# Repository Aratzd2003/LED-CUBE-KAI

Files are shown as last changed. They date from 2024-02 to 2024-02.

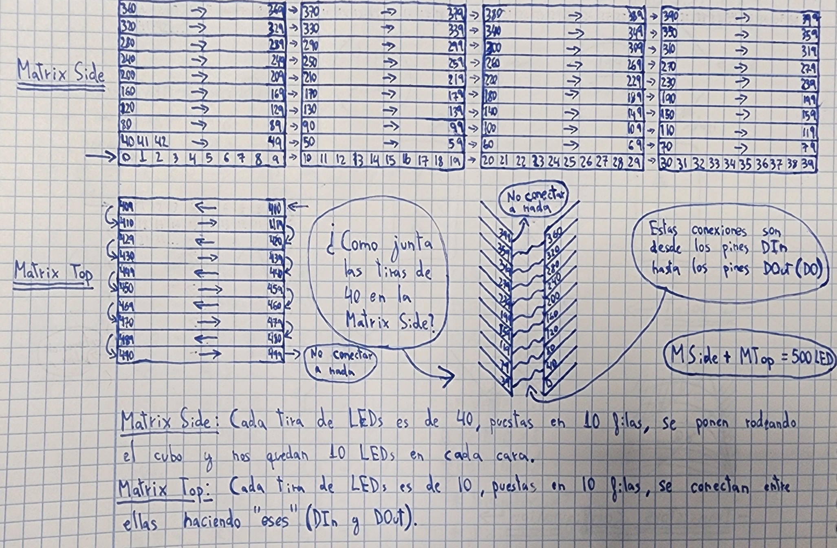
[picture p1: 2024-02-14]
LED CUBE KAI/LEDen banaketa.jpg

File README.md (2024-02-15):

# LED-CUBE-KAI

PROIEKTUAREN DESKRIBAPENA

"LED-CUBE KAI" proiektua LEDen hiru dimentsioko kuboa da, sormena, ingeniaritza eta programazioa konbinatzen dituena, ikusizko erakustaldi liluragarri bat sortzeko. Kubo formako egurrezko oinarri baten gainean eraikia, gailuak estrategikoki jarritako LED zerrendak erabiltzen ditu argien bi matrize osatzeko. Kuboaren alboetan 40 LEDeko hamar zerrenda horizontaletan eta goiko aldean 10 LEDeko hamar zerrendatan antolatuta, kuboak patroiak eta argi-efektuak sortzeko aukera zabala eskaintzen du.

5V-ko eta 30Ako bi elikadura-iturrik hornidura elektriko sendoa bermatzen dute, energia modu eraginkorrean banatuz LED matrizeen, Teensy mikrokontrolagailuaren eta Bluetooth moduluaren artean. Gainera, ikuspena hobetzeko eta LED bakoitza argi eta garbi bereizteko, argia bereizteko gelaxkak eta akriliko opakuzko estaldura gehitu dira. Estaldura horri esker, argia dardarka sortzen da, kuboaren barne-egitura agerian utzi gabe, eta ikusizko efektu liluragarria sortzen da.

Kuboaren beheko aldean, barnean, zirkuitu inprimatuko plaka batek (PCB) Teensy, Bluetooth modulua eta konexio elektrikoak gordetzen ditu, proiektuaren elektronika zentralerako plataforma antolatu eta trinkoa eskainiz. Gordailu honetan zehaztutako dokumentazioak "LED-CUBE KAI" ren erreplikazioa errazten du, zale sutsu eta zaleei beren hiru dimentsioko LED kuboaren sorreran murgiltzeko aukera emanez.

JATORRIZKO IDEIA: Inspirazioa eta Egokitzapena

"LED-CUBE KAI" proiektua Moekoeren lan miresgarrian eta "500 LED-Pixel RGB-Brick" proiektuan oinarritzen da. Bere ideia berritzaileen inspirazioa hartu dugu, diseinua eta ikuspegia gure LED kuboa sortzeko.

https://www.instructables.com/500-LED-Pixel-RGB-Brick/



Jatorrizko proiektuaren inspirazioa:

Kuboaren diseinua:
Kuboaren hiru dimentsioko egitura hartu genuen, hainbat geruzatan banatutako LEDen zerrendekin, jatorrizko proiektuan agertzen zen bezala. Alboetan 40 LEDeko 10 zerrenda horizontal eta goiko aldean 10 LEDeko 10 zerrenda jartzea funtsezko ezaugarria izan zen.

LEDen banaketa:
LEDen banaketa eta bereizketa espezifikoari jarraitzen diogu, jatorrizko proiektuan emandako jarraibideen arabera. Erabaki horrek argi uniformea eta itxura bisualki erakargarria bermatu zituen.

Oinarriaren egitura eta PCB: Kuboaren egiturarako egurrezko oinarri bat erabiltzeko aukeran oinarritzen gara.

Egokitzapena eta hobekuntzak:

Dimentsio pertsonalizatuak:
Jatorrizko sortzaileak emandako neurrietan oinarritzen bagara ere, kuboaren dimentsioetan doikuntzak egin ditugu gure lehentasun estetikoetara eta eskuragarri ditugun materialetara egokitzeko; adibidez, ertzen dimentsioetan doikuntzak egin behar izan genituen.

Elementu berriak sartzea:
Ezaugarri berriak gehitu ditugu, hala nola kuboaren barruko osagaien banaketa edo kuboaren egurrezko oinarria, orain kuboaren plakan marraztutako gure logoa ikusten uzten diguna.

Inspirazio-iturria ezagutzean eta jatorrizko sortzaileari eskerrak ematean, haren lana aitortzeaz gain, LEDen eta proiektu elektronikoen zale sutsuen komunitatearen barruan ezagutzak trukatzen laguntzea ere bilatzen dugu. Jatorrizko proiektuaren ikuspegi, egokitzapen eta hedapen berri hori "LED-CUBE KAI" delakoan islatzen da, eta orain beste sortzaile eta zale batzuk inspiratzea espero da, LEDen kuboak eraikitzeko esperientzia pertsonalizatuan murgiltzeko.

ARAZOAK ETA KONPONBIDEAK PROIEKTUAN

1. Arazoa: Konexioak eta zirkuitulaburrak

Deskribapena: Led-ak elikatze iturrira konektatu aurretik beharrezkoa da zehatz mehatz begiratzea ea ondo dauden konexioak, bestela zierkuito laburra gerta liteke eta ondorioz led-ak hautsi daitezke.

Konponbidea: Elikatze iturria ezarri aurretik berrikuspen zehatz bat egin eta konexioak guztiak ziurtatu behar dira. 

2. Arazoa: Kuboko anguluen neurri txarra

Deskribapena: Hasiera baten aristen anguluek eta ixki ez zuten bat egiten.

Konponbidea: Kuboa montatzekoan, alboko piezekin eta aristen alguluen neurtzen hasi horrela biak batzerakoan elkarketa bikaina lortuko da.  

3. Arazoa : Led tira ez dabil

Deskribapena: Hasiera baten LED tira ez zen piztutzen, non konexio arazoekin liteke.  

Konponbidea: LED tira kendu eta kodigoaren bitartez ziurtatu ea funtzionamendua ondo dijoala, horrekin ikusi daiteke badijoazten edo ez.

4. Arazoa: PCB-ren diseinua

Deskribapena: Hainbat arazo egon daitezke plakako elemntuak ondo ez badira neurtzen edo haien konexioak zein espazioak kontuan hartzen.

Konponbidea: Plakak fresatu aurretik, planifikatu arretaz elementuen eta konexioen banaketa. Ziurtatu diseinu argia duzula eta berrikusi konexio guztiak fabrikazioaren aurretik.

5. Arazoa: #fastled liburutegiko kodea ulertzeko zailtasuna.

Deskribapena: #fastled liburutegia erabiltzean kodea ulertzeko zailtasuna aurkitu da. Interneten laguntza bilatu eta hainbat saiakera egin ondoren, LEDekin efektu desberdinak lortu ziren.

Konponbidea: #fastled liburutegiarekin kodea ulertzeko, bilatu laguntza online baliabideetan eta egin probak. Kodeen karpetan, erreferentziako behin betiko kodea sortu aurretik probak eta esperimentuak utzi dira.

¡¡¡GARRANTZITSUA!!!
5. Arazoa: Goiko metriza

Deskribapena: Konexio guztiak amaituzean eta PCB edukita, arazoak izaten hasi ginen goiko led-en matrizearekin, esaterako kolore urdinez jartzea eskatzen genionean beste kolore batzuetako ezartzen zen.

Konponbidea: Proba asko egin eta zirkuitu elektriko guztia eta kodea modu exaustiboan aztertu ondoren, elikadura-iturrien arazoa zela ondorioztatu genuen, eta LEDak elikatzen zituen iturria aldatu eta beste bat jarri genuen. Aldaketa hori egitean, ondo funtzionatzen zuen. Beraz, ez dizuegu gomendatzen guk erosten ditugun elikadura-iturri berberak erostea, ezaugarri berberak dituzten iturri batzuk bilatzea (5V eta 30A) eta kuboaren barruko espazioarekin bat datorren tamaina dutenak.

MUNTATZEKO JARRAITU BEHARREKO PAUSOAK

Ezer baino lehen, proiektua egiteko materialak beharko ditugu. "Materialen zerrenda" izeneko karpetan erantsi dizkizuegu. Material batzuen zehaztapen zehatzak, berriz, argazkiak emango dizkizuegu montagean (adibidez, ertzak).

Ez ditugu zehaztu acrylic glass-en neurriak, uste dugulako hobe duzuela dena muntatzen amaitu ondoren lortzen dituzuen neurrietara egokitzea, baina jakin nahi izanez gero, honako hauek dira:

- 36.6 cm/34.8 cm x2
- 36.6 cm/35.8 cm x2
- 34.8 cm/34.8 cm

Lehendabizi kaxa eta xaflak montatuko ditugu. Kaxa egurrezko bost piezataz osatuta dago (basea gehituta, pieza handiena dela). 

Alboko aldeak:
x2 pieza 25,2cm x 29,6cm x 1,0cm (pieza "txikiak")

x2 pieza 29,6cm x 27,2cm x 1,0cm (pieza "handiak")

x1 pieza 27,2cm x 27,2cm x 1,0cm ("goiko" pieza)

x1 pieza  34,0cm x 34,0cm x 1,5cm ("baseko" pieza)





Ertzetako zuloek, haien artean ahokatzeko, 3,4cm-ko tartea dute zulo bakoitzaren eta sakoneraren artean piezaren zabaleraren erdiaren artean. Ondo pentsatu zein zentzutan egin zenioten zuloa, denak piezaren alde berean egiten bazenituzten ezin baitzituzten sartu.





Kuboaren neurriak (kanpokoak, ez barruko kuboarenak) pixelek LEDen zerrendan duten distantziaren arabera zehazten dira (10 pixel zabal alde bakoitzean). Kasu honetan pixelek 3,4cm-ko distantzia dute, beraz, kuboak 34 x 34 x 34cm neurtu behar ditu eta ertzak . Denbora asko aurreztuko duzu dimentsio horiek erabiliz, ez baituzu pixel bakoitzaren ondoren zerrenda moztu eta kable txiki batekin berriro lotu beharko.

Behar bezala lan egin behar duzu, akriliko-kaxa ezin hobeto egokitzen baita egurrezko kaxaren goialdean. Askoz errazagoa bihurtzen da boluntario batzuekin zure inguruan, edo, besterik gabe, erabili marko tenkagailu bat guk egin genuen bezala. Zurezko itsasgarriarekin "KUBOAREN IZKINAK" egiten dituzten "ERTZAK" itsatsiko ditugu. Nahiko zaila da 45 gradu lortzea gelaxkak zedarritzen dituzten ertz-punten angeluan. Horrela, adi egon eta pieza bakoitza ondo diseinatu eta egin behar da.



Ertzak egiteko, piezak neurri egokiekin beharko ditugu. Gure kasuan, ez ditugu erreferentzia gisa erabili dugun proiektuko neurri berak erabili. Horretarako, fitxategi bat utziko dugu erantsita, laser ebakigailuarekin (XTOOL D1 PRO) ebakitzeko erabili ditugun piezekin. Piezen neurriak honako hauek dira
:

Buztan osoa lehor dagoenean (kuboaren ertzeko ertzetakoa) eta gelaxken ertzak aparte muntatu direnean, led-ak kuboan jarriko ditugu kontu handiz, erdian gera daitezen, gelaxken karratuak kontuan hartuta, argazki honetan bezala erdian gera dadin.

(argazkia ez da azken emaitza, ertzak jarri ditugu adibide gisa ikus dadin.)

LED tirak egiteko, alboetarako 40 pixeleko 10 LED zerrenda moztu behar dira, eta kontu handiz ibili behar da horiek jartzerakoan; izan ere, ledetako gezi guztiek zentzu berean egon behar dute argazki honetan bezala.


Badago fitxategi bat "LEDen banaketa" bertan ikusdezakezutela LEDen banaketa eta konexioa zehatzago ikus daiteke.

Jarraian, elikadura-iturriak diagonaleko bi ixkinatan jarri ditugu, kuboko pisua orekatzeko, ondoren led-ekiko konexioak egin beharko dira. (BETI ITURRIEKIKO PARALELOAN, SERIEAN egiten badituzue LED guztiak intentsitate berarekin argiztatuko ez balira). LEDen elikadura-kableak kutxatik ateratzen dira LED zerrenda bakoitzetik gertu dauden zulo txiki batzuen bidez.

Elikadura-iturri bat 40 LEDeko 6 zerrenda elikatzeaz arduratuko da, eta bestea 40 LEDeko 4 tira eta 10 LEDeko 10 tira elikatzeaz (240+ (160+100) = 500 LED)




Hau izango zan eskema eltrikoa tensy, bluetooth, elikatze iturri eta led matrizak konektatuta.



Eta azkenik, kaxaren oinarriko taulak zulo bat du erdian, plaka torlojututa dago zuloa estaltzeko moduan, eta plakaren osagaietan (kuboaren barrurantz daudenak) aldaketa bat egin nahi baduzu, torlojuak plakatik kendu eta manipulatu ahal izango duzu, edo kuboaren barruko kableatuan aldaketa bat egin nahi baduzu, xafla estaltzen duen zuloaren manipulazio atrableak egin ditzakezu, gure kasuan zuloaren neurriak 80x140koak dira, baina plakaren berezko buestraren tamainara egokitu behar duzue. Halaber, oinarri/hanka bat jarri diegu burko txikiei, lurra ukitu ez dezan, marrarik egin ez dezan.

20240207_104935 (1)

Conexiones foto
PCB foto

*SOFTWARE*

Softwarearen atalean appinventor bat dugu hasteko. Web-orri horretan, mugikorrerako zeure aplikazioa sor dezakezu, "APPINVENTOR" karpetaren barruan APK fitxategia daukazue, gure aplikazioa nahi baduzue ere, eta zuen kodeari egokitu nahi badiozue, AIA fitxategia pasako dizuegu, AIA fitxategia irekitzeko, beheko irudian erakusten den atalean fitxategia appinventor (google) barruan igo behar duzue.



Bideo bat duzue appinventor nola funtzionatzen duen azaltzeko, APPINVENTOR/Bideoak karpetaren barruan dago. Gure kasuan, beheko irudian ikus dezakezuenez, bluetooth-erako beharrezkoak diren blokeak ditugu , gainerako guztiak botoia sakatuz bidaliko ditugun letrak dira. Zehazki, letra horiek bidaliko ditugu, Teensy (arduino) kodean zenbait ekintza egiteko baldintza jarri dugulako, hala nola koloretako ekorketak egiteko edo kolore bateko kuboa pizteko.



Jarraian, zatika azalduko dut Teensy-ren kode definitzailea, Arduinoren idazkeran dagoena (LEDCUBE_0.7v).

Kodean jarriko dugun lehenengo gauza erabiliko ditugun liburutegiak dira, FastLED liburutegia liburutegien kudeatzailearengana joan eta "FastLED NeoPixel" deritzona deskargatu behar duzue.





Behin hori eginda, kodean ikus dezakegun hurrengo gauza pin-esleipena da (bluetooth eta led-en kontrola), eta, ondoren, adibidez, led-en matrizeen tamaina definitzeko erabiltzen ditugun aldagaiak ditugu, guztia banatu ditugun moduaren araberakoa da, gure kasuan 10x40ko matrizea eta 10x10eko matrizea dira, gainerakoak FastLED liburutegia CRGB led1 gisa funtzionatzeko jarri behar diren aldagaiak dira [LED_COUNT1], 1. matrizeari led-kantitatea esleitzea bezala dena, eta gainerakoak aldagaiak dira, bakoitzak bere atalean behar dituen balioekin; adibidez, snakeLength aldagaia Snake jokoaren sugearen pixelen tamaina da.



Jarraian, void setupa eta loop-a ditugu, setupean led-en zerrenda/matrize bakoitzaren adierazpena, serialaren (monitore seriala) eta sw-aren (bluetooth seriala) abiadurak ezarriko ditugu eta kuboa hasiko dugu led-ak itzaliz.
Gero, loopean dugun gauza bakarra baldintza bat da, bluetooth bidez zerbait jasotzen badugu, balio hori monitore serialean idatziko dugu (funtzio hau bluetooth bidez balio zuzenak iristen zaizkigula egiaztatzeko da batez ere) eta gordetako bluetoothak jasotako balioa luzatuko duen void executeBluetoothCommand exekutatuko dugu.



Zuei azaltzeko, lehenik void batzuk saltatuko ditugu, eta lehenik garrantzitsuenera joango gara, eta dena kontrolatzen duenera, executeBluetoothCommand, bluetooth delakoagatik zerbait jaso ondoren, jasotako balioa duen "case" a bakarrik sartu eta exekutatuko dugu. Lehenengo case horiek kolore zehatzetako LED guztiak pizten dituzte, sinpleagoak direnak, fill_solid (zerrenda hautatua, leds kantitatea, eta zer koloretakoa pizten ditugun), FastLED.show da zerrendetan erakustea zer aldaketa egin dugun led-etan, gauzak jarri arren led-ek ezer egiten ez badute.



Gero, beste funtzio bat dugu: argi zuria ekortzea led zerrenda osoan, 0 LEDetik 400 LEDera, eta 400 LEDera iristean, beste 100ak pizten ditu aldi berean, eta gero itzaltzen da, ordena okerragoan.



Ondoren, hurrengo case-ak ekorketa bertikalak dira, bakoitza kolore zehatz batekoa.



Eta, azkenean, hiru case ditugu, beren void propioa dutenak, void bakoitzaren azalpenaren argazkietan ikusten diren kode-lerroetan aurki ditzakegu.



DrawCreeperHeaden, 1. matrizearen barruan, aukeratutako koloretik piztuko ditugun led-ak (berdea, kasu honetan) zero batzuekin esleituko ditugu, batzuk piztuko dira, eta banaketa horren emaitza creeper baten aurpegia da, mundu osoan Minecraft izeneko jolas ospetsuko izaki bat.



Void honetan koloretako begizta bat egiten dugu, kolorearen eta kolorearen artean transizion bat dago, non egungo kolorea apurka-apurka itzaltzen den eta behin itzaliz gero hurrengo koloretik pixkanaka pizten den, void hau eta snake kolorearena azaltzen zailagoak dira, baldin eta ez bazaizue nahikoa egiten case bakoitzean egiten ari garen azalpenari buruz zenbait iruzkin egiten dituzue Españolezko kode gehienetan, zati bakoitzean egiten ari dela azalduz.





Void Snake kodearen zatirik luzeena da, logika asko dituelako jolasa delako, eta, beraz, hitz egiten ari naizenaren irudiak ikusi nahi badituzue, ikus dezakezue LEDCUBE_0.7v kodearen amaieran. Hasteko, sugearen eta sagarraren hasierako posizioak esleitzen ditugu, gero sugea mugitzen hasteko zentzuari ekiten diogu, behean (kodean gorantz jartzen du, baina hori da led-en distrubuizionaren logikagatik kodearentzat matrizea errebesean dagoela, horregatik lehen creeperraren aurpegia errebesean jartzen dugu, gero kuboan ondo kokatuta ikusteko, baizik eta rebesean ikusten da), gero sugearen mugimendu-logika eta kolisioaren egiaztapena ditugulako.

Hori izan da kuboan erabili dugun azken kodeari buruzko azalpena, baina kodeen karpetan LEDekin eta FastLED liburu-dendarekin funtzionamendu- eta logika-probak egiteko erabili ditugun beste kadigo batzuk dituzue.

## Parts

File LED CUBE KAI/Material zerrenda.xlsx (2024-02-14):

Material zerrenda |  |  | No teneis porque comprar el producto desde el link que os proporcionamos, mientras cumpla la caracteristicas que os hemos dado os sirve
MATERIALA | KANTITATEA | DESKRIPZIOA
Elikatze-iturria (https://www.amazon.es/HAI-Adaptador-Corriente-Transformador-alimentaci%C3%B3n/dp/B07Q2VPPL1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) | 2 | 5V-30A-150W
TENSY4.0 (https://www.amazon.es/Teensy-4-0-Con-Pins/dp/B08259KDHY?adgrpid=65254215289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) | 1 | 4.0
Teensy audioboard (https://www.amazon.com/Audio-Adaptor-Board-Teensy-4-0/dp/B07Z6NW913) | 1 | adaptadora de audio 4.0 | (Opcional, nosotros no lo hemos usado, pero si quieres hacer cosas con sonido en el cubo te hace falta esta placa para el teensy)
Bluetooth MODULE | 1 | 10,1 x 6 x 2 cm; 10 gramo
Beira akrilikoa | 1 |  | Comprar lo necesario para las medidas que os hemos dado
Egurra | 1
Egur-itsasgarria (https://www.amazon.es/Rayt-036-03-Botell%C3%ADn-multiuso-materiales/dp/B00U1OL4L4?adgrpid=57755855978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) | 1 | 125gr
Kristal-itsasgarria (https://www.amazon.es/S-PolyBond%C2%AE-plexigl%C3%A1s%C2%AE-pegamento-soldadura-plexigl%C3%A1s/dp/B07PNYJDZ7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) | 1 | Acrylglas/Plexiglas kleber | Usar este o un pegamento que os combezca, LOCTITE tambien esta bien
USB portua (https://es.rs-online.com/web/p/conectores-usb/9160221) | 1 |  | Un puerto hembra-hembra con agujeros para fijarlo en la PCB
Marko-tentsatzailea (https://www.amazon.es/Stanley-0-83-100-Tensor-cinta-Bailey/dp/B001DZVNE8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) | 1
Led tirak (https://es.aliexpress.com/i/1005003385886122.html) | 2x5metro, 1x2metro | 500 WS2812 LEDs 30px/m | 500 LEDs
Torlojuak (https://www.amazon.es/Tornillos-Autorroscantes-Surtido-Autotaladrantes-Redonda/dp/B099F5NLS7) | 1 |  | Comprar la cantidad y longitud que necesiteis, nosotros hemos usado de 35mm, 30mm y 20mm
Erregletak (https://www.amazon.es/CABLEPELADO-el%C3%A9ctricos-el%C3%A9ctrico-Intensidad-Transparente/dp/B074PSBLF8) | 20 | 6mm | Nosotros compramos 2 grupos de 10 regletas
Kableak (https://www.amazon.es/Electronica-Alambre-Esta%C3%B1ado-Conectores-Bricolaje/dp/B08P8H3P2Y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) | 1 | 10m | Cable electrico de 2,5 de grosor
Bridak (https://www.amazon.es/intervisio-Bridas-Plastico-Cables-Piezas/dp/B074LSPSQS) | 1 | 100 pieza txuri | Compramos un paquete de 100, pero comprar las que os hagan falta
Cable Switch (https://www.amazon.es/Adaptador-Extensi%C3%B3n-Alimentaci%C3%B3n-Interruptor-L%C3%A1mparas/dp/B0B3D82RP3) | 1 | 30cm | Para hacer el cable de alimentacion podeis comprar uno ya echo o si quereis que tenga un iterruptor podeis haceros vosotros el cable, comprais cable, el conector y el interruptor y lo montais
Kablea (https://www.amazon.es/Cable-alimentacion-IEC-320-acodado-Metros/dp/B08K6THF8X?sp_csd=d2lkZ2V0TmFtZT1zcF9hdGY) | 1 | 1m
Cable Micro USB | 1
Cable USB Hembra-Hembra | 1

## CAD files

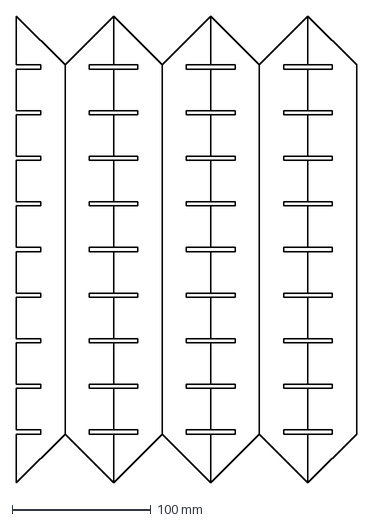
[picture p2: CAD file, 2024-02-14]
LED CUBE KAI/Ebaketa-piezak/01 piezas en bloques/7 piezas interior horizontal.dxf
245.0 x 336.0 mm

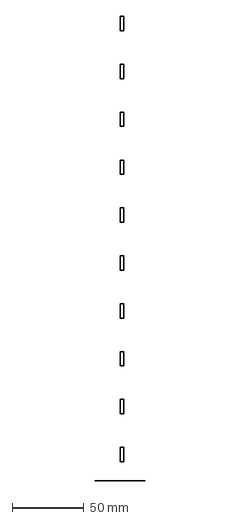
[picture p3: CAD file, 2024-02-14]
LED CUBE KAI/Ebaketa-piezak/Agujeros piezas laterales.dxf
35.0 x 323.7 mm

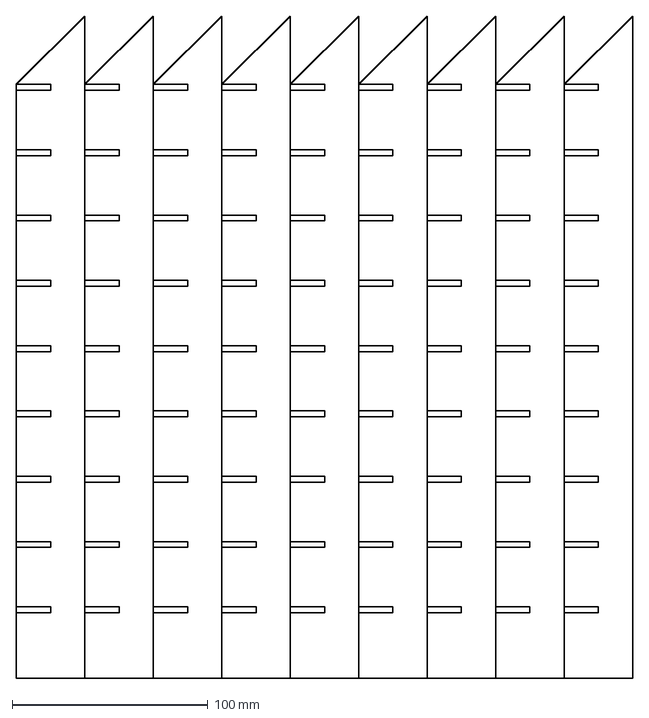
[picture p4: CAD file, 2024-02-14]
LED CUBE KAI/Ebaketa-piezak/01 piezas en bloques/9 piezas interior vertical.dxf
315.0 x 338.5 mm

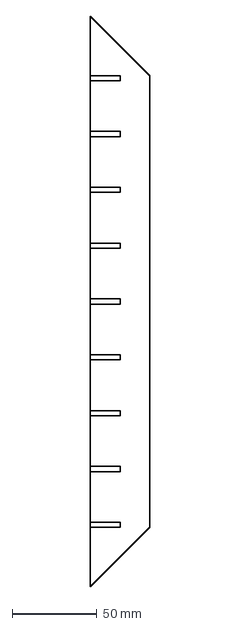
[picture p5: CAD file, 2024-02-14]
LED CUBE KAI/Ebaketa-piezak/Pieza interior horizontal I.dxf
35.0 x 336.0 mm

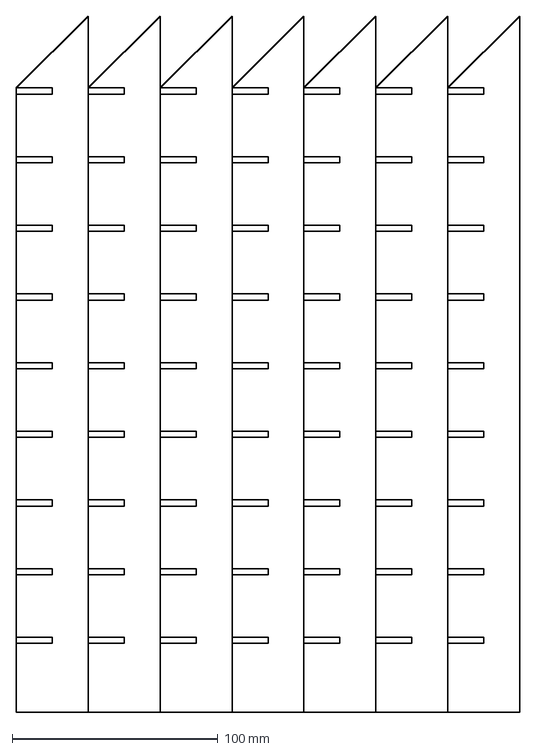
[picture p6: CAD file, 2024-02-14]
LED CUBE KAI/Ebaketa-piezak/01 piezas en bloques/7 piezas interior vertical.dxf
245.0 x 338.5 mm

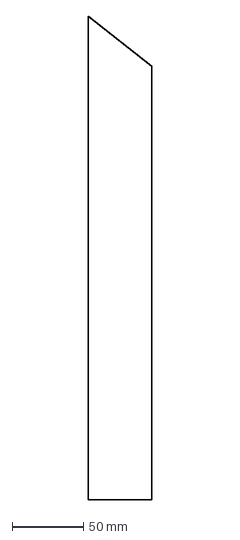
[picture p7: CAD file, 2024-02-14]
LED CUBE KAI/Ebaketa-piezak/Pieza lateral vertical.dxf
45.0 x 340.0 mm

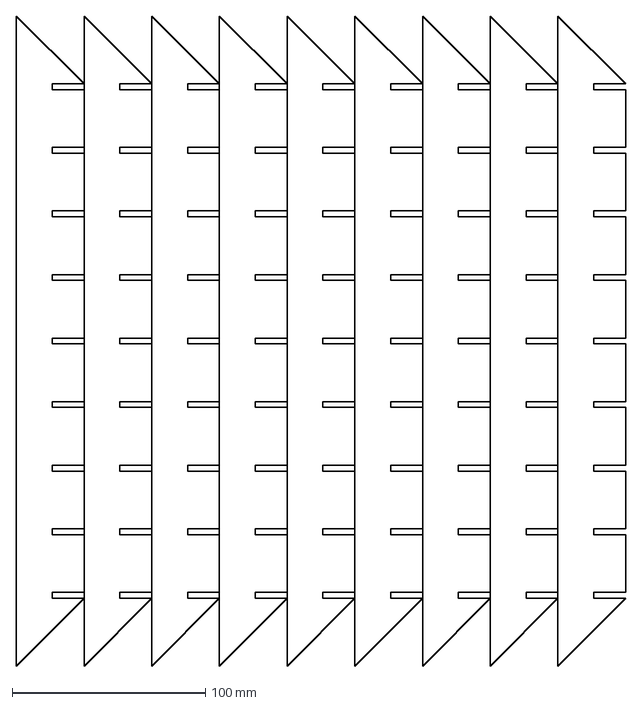
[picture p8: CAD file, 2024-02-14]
LED CUBE KAI/Ebaketa-piezak/01 piezas en bloques/9 piezas interior horizontal II.dxf
315.0 x 336.0 mm

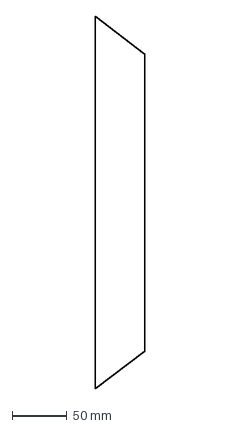
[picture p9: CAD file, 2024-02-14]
LED CUBE KAI/Ebaketa-piezak/Pieza lateral superior.dxf
45.0 x 339.9 mm

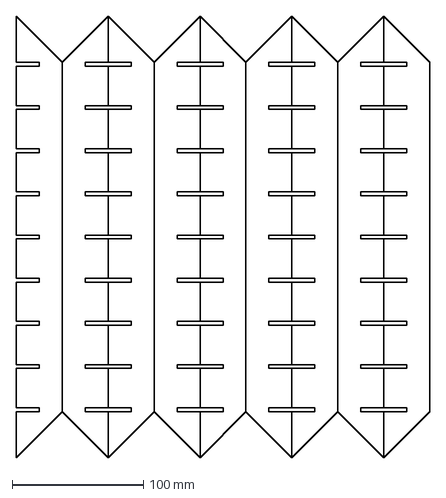
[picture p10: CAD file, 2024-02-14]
LED CUBE KAI/Ebaketa-piezak/01 piezas en bloques/9 piezas interior horizontal.dxf
315.0 x 336.0 mm

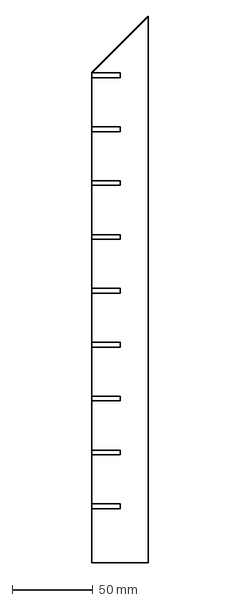
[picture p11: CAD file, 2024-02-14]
LED CUBE KAI/Ebaketa-piezak/Pieza interior vertical.dxf
35.0 x 338.5 mm

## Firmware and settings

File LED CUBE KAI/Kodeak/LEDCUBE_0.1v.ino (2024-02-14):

// Letras usadas: B, R, N, Y, G, P, M, Z, K

#include <FastLED.h>
#include <SoftwareSerial.h>

SoftwareSerial Sw(0, 1);  // RX, TX

#define LED_PIN      2  
#define NUM_ROWS     10
#define LEDS_PER_ROW 40
#define LED_COUNT    (NUM_ROWS * LEDS_PER_ROW)
#define COLOR_ORDER  GRB

CRGB leds[LED_COUNT];
CRGB color;
String actualColor;

void setup() {
  FastLED.addLeds<WS2812B, LED_PIN, GRB>(leds, LED_COUNT);
  Serial.begin(9600);
  Sw.begin(9600);
  color = CRGB::Black;
}

void loop() {
  if (Sw.available() > 0) {
    char c = Sw.read();
    Sw.print(c);
    executeBluetoothCommand(c);
  }
}

  void drawCreeperHead() {
  // Matriz 10x10 para representar la cabeza del Creeper
  int creeperHead[10][40] = {
    {1,1,1,1,1,1,1,1,1,1,1,1,1,1,1,1,1,1,1,1,1,1,1,1,1,1,1,1,1,1,1,1,1,1,1,1,1,1,1,1},
    {1,1,1,1,1,1,1,1,1,1,1,1,1,1,1,1,1,1,1,1,1,1,1,1,1,1,1,1,1,1,1,1,1,1,1,1,1,1,1,1},
    {1,1,0,0,1,1,0,0,1,1,1,1,1,1,1,1,1,1,1,1,1,1,1,1,1,1,1,1,1,1,1,1,1,1,1,1,1,1,1,1},
    {1,1,0,0,1,1,0,0,1,1,1,1,1,1,1,1,1,1,1,1,1,1,1,1,1,1,1,1,1,1,1,1,1,1,1,1,1,1,1,1},
    {1,1,1,1,0,0,1,1,1,1,1,1,1,1,1,1,1,1,1,1,1,1,1,1,1,1,1,1,1,1,1,1,1,1,1,1,1,1,1,1},
    {1,1,1,0,0,0,0,1,1,1,1,1,1,1,1,1,1,1,1,1,1,1,1,1,1,1,1,1,1,1,1,1,1,1,1,1,1,1,1,1},
    {1,1,1,0,0,0,0,1,1,1,1,1,1,1,1,1,1,1,1,1,1,1,1,1,1,1,1,1,1,1,1,1,1,1,1,1,1,1,1,1},
    {1,1,1,0,1,1,0,1,1,1,1,1,1,1,1,1,1,1,1,1,1,1,1,1,1,1,1,1,1,1,1,1,1,1,1,1,1,1,1,1},
    {1,1,1,1,1,1,1,1,1,1,1,1,1,1,1,1,1,1,1,1,1,1,1,1,1,1,1,1,1,1,1,1,1,1,1,1,1,1,1,1},
    {1,1,1,1,1,1,1,1,1,1,1,1,1,1,1,1,1,1,1,1,1,1,1,1,1,1,1,1,1,1,1,1,1,1,1,1,1,1,1,1}
  };

  // Aplicar los colores correspondientes en la matriz de LEDs
  for (int row = 0; row < 10; row++) {
    for (int col = 0; col < 40; col++) {
      int index = row * LEDS_PER_ROW + col;
      if (creeperHead[row][col] == 1) {
        // Colorear todos los píxeles en verde
        leds[index] = CRGB::Green;
      }
    }
  }

  // Mostrar la cabeza del Creeper en las primeras 10 columnas de la matriz de LEDs
  FastLED.show();
}

void executeBluetoothCommand(char command) {
  

  switch (command) {
    case 'B':
      // Azul
      color = CRGB::Blue;
      actualColor = "Blue";
      fill_solid(leds, LED_COUNT, color);
  FastLED.show();
      break;
    case 'R':
      // Rojo
      color = CRGB::Red;
      actualColor = "Red";
      fill_solid(leds, LED_COUNT, color);
  FastLED.show();
      break;
    case 'N':
      // Naranja
      color = CRGB(255, 102, 0); // Naranja
      actualColor = "Orange";
      fill_solid(leds, LED_COUNT, color);
  FastLED.show();
      break;
    case 'Y':
      // Amarillo
      color = CRGB::Yellow;
      actualColor = "Yellow";
      fill_solid(leds, LED_COUNT, color);
  FastLED.show();
      break;
    case 'G':
      // Verde
      color = CRGB::Green;
      actualColor = "Green";
      fill_solid(leds, LED_COUNT, color);
  FastLED.show();
      break;
    case 'P':
      // Rosa
      color = CRGB(255, 192, 203); // Rosa
      actualColor = "Pink";
      fill_solid(leds, LED_COUNT, color);
  FastLED.show();
      break;
    case 'M':
      // Morado
      color = CRGB::Purple;
      actualColor = "Purple";
      fill_solid(leds, LED_COUNT, color);
  FastLED.show();
      break;
    case 'Z':
      // Blanco
      color = CRGB(255, 255, 255); // Blanco
      actualColor = "White";
      fill_solid(leds, LED_COUNT, color);
  FastLED.show();
      break;
    case 'K': // APAGAR APAGAR APAGAR APAGAR APAGAR APAGAR APAGAR APAGAR APAGAR APAGAR APAGAR APAGAR APAGAR 
      // Negro (apagar todos los LEDs)
      color = CRGB::Black; // Negro
      actualColor = "Black";
      fill_solid(leds, LED_COUNT, CRGB::Black);
      FastLED.show();
      return; // No es necesario mostrar nuevamente si todos están apagados

    // BARRIDOS BARRIDOS BARRIDOS BARRIDOS BARRIDOS BARRIDOS BARRIDOS BARRIDOS BARRIDOS BARRIDOS BARRIDOS

    case 'z':
      // Barrido simultáneo desde el primer LED- de cada fila en color blanco
      for (int i = 0; i < LEDS_PER_ROW; i++) {
        for (int row = 0; row < NUM_ROWS; row++) {
          // Calcular el índice global del LED
          int index = row * LEDS_PER_ROW + i;
          
          // Cambiar el color del LED actual a Azul
          leds[index] = CRGB(255, 255, 255); // Blanco
        }
        
        // Enviar los datos a la tira de LEDs
        FastLED.show();
        
        // Esperar un corto periodo de tiempo
        delay(100); // Ajusta el valor para recorrer 10 LEDs por segundo
        
        // Apagar todos los LEDs
        for (int row = 0; row < NUM_ROWS; row++) {
          int index = row * LEDS_PER_ROW + i;
          leds[index] = CRGB::Black;
        }
      }
      FastLED.show();
      break;
    case 'b':
      // Barrido simultáneo desde el primer LED- de cada fila en color azul
      for (int i = 0; i < LEDS_PER_ROW; i++) {
        for (int row = 0; row < NUM_ROWS; row++) {
          // Calcular el índice global del LED
          int index = row * LEDS_PER_ROW + i;
          
          // Cambiar el color del LED actual a Azul
          leds[index] = CRGB::Blue;
        }
        
        // Enviar los datos a la tira de LEDs
        FastLED.show();
        
        // Esperar un corto periodo de tiempo
        delay(100); // Ajusta el valor para recorrer 10 LEDs por segundo
        
        // Apagar todos los LEDs
        for (int row = 0; row < NUM_ROWS; row++) {
          int index = row * LEDS_PER_ROW + i;
          leds[index] = CRGB::Black;
        }
      }
      FastLED.show();
      break;
      case 'r':
      // Barrido simultáneo desde el primer LED- de cada fila en color rojo
      for (int i = 0; i < LEDS_PER_ROW; i++) {
        for (int row = 0; row < NUM_ROWS; row++) {
          // Calcular el índice global del LED
          int index = row * LEDS_PER_ROW + i;
          
          // Cambiar el color del LED actual a Azul
          leds[index] = CRGB::Red;
        }
        
        // Enviar los datos a la tira de LEDs
        FastLED.show();
        
        // Esperar un corto periodo de tiempo
        delay(100); // Ajusta el valor para recorrer 10 LEDs por segundo
        
        // Apagar todos los LEDs
        for (int row = 0; row < NUM_ROWS; row++) {
          int index = row * LEDS_PER_ROW + i;
          leds[index] = CRGB::Black;
        }
      }
      FastLED.show();
      break;
      case 'n':
      // Barrido simultáneo desde el primer LED- de cada fila en color naranja
      for (int i = 0; i < LEDS_PER_ROW; i++) {
        for (int row = 0; row < NUM_ROWS; row++) {
          // Calcular el índice global del LED
          int index = row * LEDS_PER_ROW + i;
          
          // Cambiar el color del LED actual a Azul
          leds[index] = CRGB(255, 102, 0); // Naranja
        }
        
        // Enviar los datos a la tira de LEDs
        FastLED.show();
        
        // Esperar un corto periodo de tiempo
        delay(100); // Ajusta el valor para recorrer 10 LEDs por segundo
        
        // Apagar todos los LEDs
        for (int row = 0; row < NUM_ROWS; row++) {
          int index = row * LEDS_PER_ROW + i;
          leds[index] = CRGB::Black;
        }
      }
      FastLED.show();
      break;
      case 'y':
      // Barrido simultáneo desde el primer LED- de cada fila en color amarillo
      for (int i = 0; i < LEDS_PER_ROW; i++) {
        for (int row = 0; row < NUM_ROWS; row++) {
          // Calcular el índice global del LED
          int index = row * LEDS_PER_ROW + i;
          
          // Cambiar el color del LED actual a Azul
          leds[index] = CRGB::Yellow;
        }
        
        // Enviar los datos a la tira de LEDs
        FastLED.show();
        
        // Esperar un corto periodo de tiempo
        delay(100); // Ajusta el valor para recorrer 10 LEDs por segundo
        
        // Apagar todos los LEDs
        for (int row = 0; row < NUM_ROWS; row++) {
          int index = row * LEDS_PER_ROW + i;
          leds[index] = CRGB::Black;
        }
      }
      FastLED.show();
      break;
      case 'g':
      // Barrido simultáneo desde el primer LED- de cada fila en color verde
      for (int i = 0; i < LEDS_PER_ROW; i++) {
        for (int row = 0; row < NUM_ROWS; row++) {
          // Calcular el índice global del LED
          int index = row * LEDS_PER_ROW + i;
          
          // Cambiar el color del LED actual a Azul
          leds[index] = CRGB::Green;
        }
        
        // Enviar los datos a la tira de LEDs
        FastLED.show();
        
        // Esperar un corto periodo de tiempo
        delay(100); // Ajusta el valor para recorrer 10 LEDs por segundo
        
        // Apagar todos los LEDs
        for (int row = 0; row < NUM_ROWS; row++) {
          int index = row * LEDS_PER_ROW + i;
          leds[index] = CRGB::Black;
        }
      }
      FastLED.show();
      break;
      case 'p':
      // Barrido simultáneo desde el primer LED- de cada fila en color rosa
      for (int i = 0; i < LEDS_PER_ROW; i++) {
        for (int row = 0; row < NUM_ROWS; row++) {
          // Calcular el índice global del LED
          int index = row * LEDS_PER_ROW + i;
          
          // Cambiar el color del LED actual a Azul
          leds[index] = CRGB(255, 192, 203); // Rosa
        }
        
        // Enviar los datos a la tira de LEDs
        FastLED.show();
        
        // Esperar un corto periodo de tiempo
        delay(100); // Ajusta el valor para recorrer 10 LEDs por segundo
        
        // Apagar todos los LEDs
        for (int row = 0; row < NUM_ROWS; row++) {
          int index = row * LEDS_PER_ROW + i;
          leds[index] = CRGB::Black;
        }
      }
      FastLED.show();
      break;
      case 'm':
      // Barrido simultáneo desde el primer LED- de cada fila en color morado
      for (int i = 0; i < LEDS_PER_ROW; i++) {
        for (int row = 0; row < NUM_ROWS; row++) {
          // Calcular el índice global del LED
          int index = row * LEDS_PER_ROW + i;
          
          // Cambiar el color del LED actual a Azul
          leds[index] = CRGB::Purple;
        }
        
        // Enviar los datos a la tira de LEDs
        FastLED.show();
        
        // Esperar un corto periodo de tiempo
        delay(100); // Ajusta el valor para recorrer 10 LEDs por segundo
        
        // Apagar todos los LEDs
        for (int row = 0; row < NUM_ROWS; row++) {
          int index = row * LEDS_PER_ROW + i;
          leds[index] = CRGB::Black;
        }
      }
      FastLED.show();
      break;
      case 'Q':
      // Dibujar la cabeza del Creeper en el primer bloque 10x10 de la matriz
      drawCreeperHead();
      break;
  }
}

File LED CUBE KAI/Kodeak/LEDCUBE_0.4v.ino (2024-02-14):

#include <FastLED.h>
#include <SoftwareSerial.h>

SoftwareSerial Sw(0, 1);  // RX, TX

#define LED_PIN1     2
#define LED_PIN2     5  // Agregado para la segunda tira de LEDs
#define NUM_ROWS1    10
#define NUM_ROWS2    10  // Número de filas para la segunda tira de LEDs
#define LEDS_PER_ROW1 40
#define LEDS_PER_ROW2 10  // Número de LEDs por fila para la segunda tira de LEDs
#define LED_COUNT1   (NUM_ROWS1 * LEDS_PER_ROW1)
#define LED_COUNT2   (NUM_ROWS2 * LEDS_PER_ROW2)
#define COLOR_ORDER  GRB

// Definir el rango específico de LEDs
#define INICIO_RANGO1 0
#define FIN_RANGO1   399
#define INICIO_RANGO2  0 // El rango para la segunda tira comienza después de la primera
#define FIN_RANGO2   99  // Ajusta según sea necesario

int columna1[] = {0, 40, 80, 120, 160, 200, 240, 280, 320, 360};

CRGB leds1[LED_COUNT1];
CRGB leds2[LED_COUNT2];  // Arreglo para la segunda tira de LEDs
CRGB color;
String actualColor;

  // Variables para apagado y encendido con atenuacion de los barridos
  int numPasosAtenuacion = 10; 
  int duracionTotal = 100;  

  // Variables para lavaLampEffect
  int totalDuration = 5000;  // 5 segundos
  int delayBetweenColors = 200;  // Retardo entre cambios de color
  int currentColorIndex = 0;  // Índices de colores actuales
  int nextColorIndex = 1;  //y siguientes

void setup() {
  FastLED.addLeds<WS2812B, LED_PIN1, GRB>(leds1, LED_COUNT1);
  FastLED.addLeds<WS2812B, LED_PIN2, GRB>(leds2, LED_COUNT2);
  Serial.begin(9600);
  Sw.begin(9600);
  color = CRGB::Black;
}

void loop() {
  if (Sw.available() > 0) {
    char c = Sw.read();
    Serial.print("Received character: ");
    Serial.println(c);
    executeBluetoothCommand(c);
  }
}
void lavaLampEffect() {
  // Colores de la lámpara de lava
  CRGB lavaColors[] = {CRGB::Red, CRGB::Orange, CRGB::Yellow, CRGB::Green, CRGB::Blue, CRGB::Purple};

// Índices de colores actuales y siguientes
  int currentColorIndex = 0;
  int nextColorIndex = 1;

  // Tiempo de inicio del efecto
  unsigned long startTime = millis();

  // Bucle que se ejecuta indefinidamente hasta recibir una "H" por Bluetooth
  while (true) {
    // Duración total de la transición gradual entre colores
    int transitionDuration = 100;  // 2 segundos
    // Número de pasos para la transición gradual
    int numSteps = 100;

    // Apagar gradualmente
    for (int i = 255; i >= 165; i--) {
      fadeToBlackBy(leds1, LED_COUNT1, 10);  // Ajusta el valor de atenuación según sea necesario
      FastLED.show();
      delay(transitionDuration / numSteps);
    }

    // Transición gradual entre colores actuales y siguientes
    for (int step = 0; step < numSteps; step++) {
      float ratio = float(step) / float(numSteps);
      CRGB currentColor = blend(lavaColors[currentColorIndex], lavaColors[nextColorIndex], ratio);

      // Aplicar el color gradualmente a todos los LEDs
      fill_solid(leds1, LED_COUNT1, currentColor);

      // Mostrar los datos en la tira de LEDs
      FastLED.show();

      // Retardo entre pasos de la transición gradual
      delay(transitionDuration / numSteps);
    }

    // Actualizar índices de colores para la siguiente transición
    currentColorIndex = nextColorIndex;
    nextColorIndex = (nextColorIndex + 1) % (sizeof(lavaColors) / sizeof(lavaColors[0]));

    // Verificar si se ha recibido una "H" por Bluetooth
    if (Sw.available() > 0) {
      char c = Sw.read();
      if (c == 'H') {
        // Detener el efecto y apagar los LEDs
        fill_solid(leds1, LED_COUNT1, CRGB::Black);
        FastLED.show();
        break;
      }
    }
  }
}

  void drawCreeperHead() {
  // Matriz 10x10 para representar la cabeza del Creeper
  int creeperHead[10][40] = {
    {1,1,1,1,1,1,1,1,1,1,1,1,1,1,1,1,1,1,1,1,1,1,1,1,1,1,1,1,1,1,1,1,1,1,1,1,1,1,1,1},
    {1,1,1,1,1,1,1,1,1,1,1,1,1,1,1,1,1,1,1,1,1,1,1,1,1,1,1,1,1,1,1,1,1,1,1,1,1,1,1,1},
    {1,1,1,0,1,1,0,1,1,1,1,1,1,1,1,1,1,1,1,1,1,1,1,1,1,1,1,1,1,1,1,1,1,1,1,1,1,1,1,1},
    {1,1,1,0,0,0,0,1,1,1,1,1,1,1,1,1,1,1,1,1,1,1,1,1,1,1,1,1,1,1,1,1,1,1,1,1,1,1,1,1},
    {1,1,1,0,0,0,0,1,1,1,1,1,1,1,1,1,1,1,1,1,1,1,1,1,1,1,1,1,1,1,1,1,1,1,1,1,1,1,1,1},
    {1,1,1,1,0,0,1,1,1,1,1,1,1,1,1,1,1,1,1,1,1,1,1,1,1,1,1,1,1,1,1,1,1,1,1,1,1,1,1,1},
    {1,1,0,0,1,1,0,0,1,1,1,1,1,1,1,1,1,1,1,1,1,1,1,1,1,1,1,1,1,1,1,1,1,1,1,1,1,1,1,1},
    {1,1,0,0,1,1,0,0,1,1,1,1,1,1,1,1,1,1,1,1,1,1,1,1,1,1,1,1,1,1,1,1,1,1,1,1,1,1,1,1},
    {1,1,1,1,1,1,1,1,1,1,1,1,1,1,1,1,1,1,1,1,1,1,1,1,1,1,1,1,1,1,1,1,1,1,1,1,1,1,1,1},
    {1,1,1,1,1,1,1,1,1,1,1,1,1,1,1,1,1,1,1,1,1,1,1,1,1,1,1,1,1,1,1,1,1,1,1,1,1,1,1,1}
  };
  fill_solid(leds2, LED_COUNT2, CRGB::Green);
  // Aplicar los colores correspondientes en la matriz de LEDs
  for (int row = 0; row < 10; row++) {
    for (int col = 0; col < 40; col++) {
      int index = row * LEDS_PER_ROW1 + col;
      if (creeperHead[row][col] == 1) {
        // Colorear todos los píxeles en verde
        leds1[index] = CRGB::Green;
      }
    }
  }

  // Mostrar la cabeza del Creeper en las primeras 10 columnas de la matriz de LEDs
  FastLED.show();
}
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
